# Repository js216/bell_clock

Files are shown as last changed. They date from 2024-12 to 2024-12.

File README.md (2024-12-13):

# Alarm clock with a real bell

These are the design files for a simple three-button alarm clock.

- `3d`: FreeCAD files for custom-fabricated parts
- `firmware`: code that runs on the clock Arduino
- `pcb`: KiCad files for the clock motherboard
- `top_plate`: KiCad files for the "front panel"

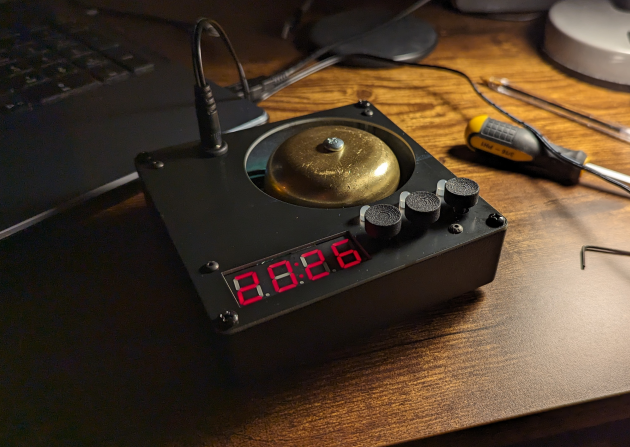
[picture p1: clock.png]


### Using the clock

#### Turning alarms on/off

Next to the time display, there are three buttons, each with an LED above it
associated with one of the three possible alarms.

A short press on these buttons cycles between three alarm modes for each of the
three alarms: alarm (and LED) off; single-chime mode (LED glows red); continuous
chime mode (LED glows green).

#### Setting the time

Pressing the first two buttons (i.e., left and middle button) simultaneously,
the time display begins flashing, signifying we're now in time setting mode. The
left button increments hours, the middle button increments minutes (resetting
seconds whenever it is pressed), and the right button is the "enter" button,
accepting the new time value.

#### Showing seconds

Pressing the middle and right buttons simultaneously, the display changes from
the usual HH:MM to MM:SS for five seconds.

#### Offset correction

The clock crystal is not perfect, and can be either fast or slow. To correct for
that, it is possible to either add or drop seconds periodically.

To enter the offset correction mode, press all three buttons simultaneously. The
display begins flashing very quickly, signifying we're in offset correction
mode. Left decrements the value, the middle button increments the value, and the
right button accepts the value.

The meaning of the offset value is as follows. For positive values, the time is
moved forward by a second every 433 minutes multiplied by the value. For
negative values, the time is moved backwards (i.e., the clock is slowed down) by
one second every 433 minutes multiplied by the absolute value of the offset
correction setting.

For example, if the offset correction value is set to -5, this means that every
5 times 433 minutes (approx 72.17 hours) a second is lost.

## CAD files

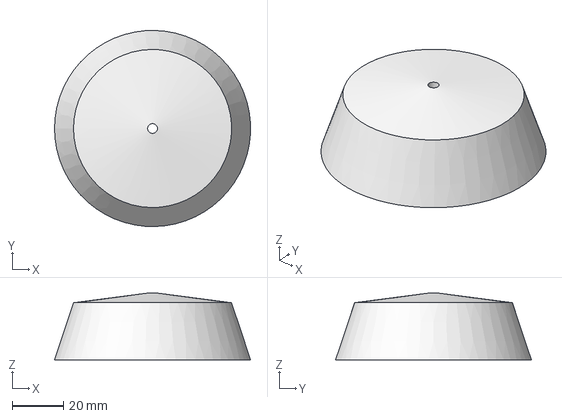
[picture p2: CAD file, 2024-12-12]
3d/bell.step
76.1 x 76.2 x 26.0 mm

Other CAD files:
3d/bell.FCStd

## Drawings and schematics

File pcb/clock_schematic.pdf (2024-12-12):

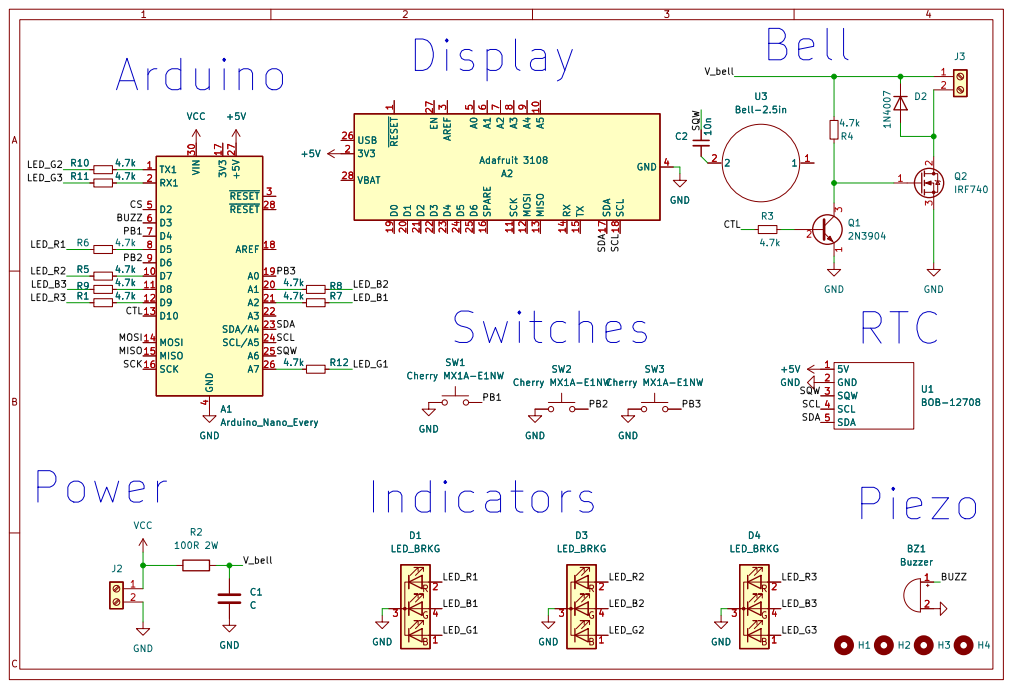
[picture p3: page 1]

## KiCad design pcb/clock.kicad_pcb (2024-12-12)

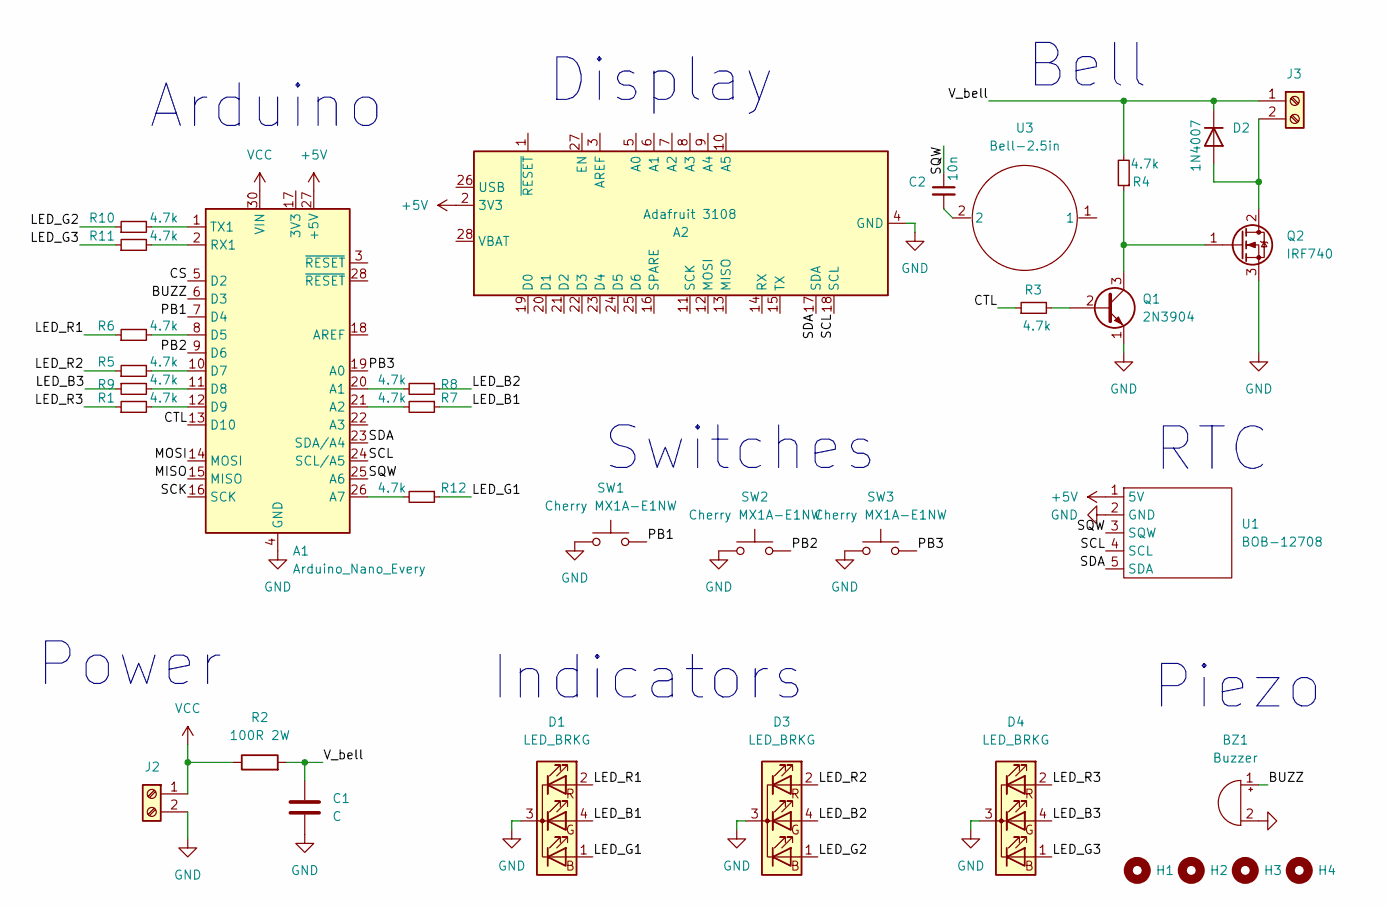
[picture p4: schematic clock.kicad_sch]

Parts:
A1: Arduino_Nano_Every; Arduino_Nano
A2: Adafruit 3108; Adafruit_Feather
BZ1: Buzzer; CP_Radial_Tantal_D10.5mm_P5.00mm
C1: C; CP_Radial_D10.0mm_P5.00mm
C2: 10n; CP_Axial_L10.0mm_D4.5mm_P15.00mm_Horizontal
D1, D3, D4: LED_BRKG; LED_D5.0mm-4_RGB
D2: 1N4007; D_DO-41_SOD81_P10.16mm_Horizontal
H1, H2, H3, H4: MountingHole; MountingHole_3.2mm_M3
J2, J3: Screw_Terminal_01x02; TerminalBlock_bornier-2_P5.08mm
Q1: 2N3904; TO-92_Inline
Q2: IRF740; TO-220-3_Horizontal_TabDown
R1, R3, R4, R5, R6, R7, R8, R9, R11, R12: 4.7k; R_Axial_DIN0207_L6.3mm_D2.5mm_P10.16mm_Horizontal
R2: 100R 2W; R_Axial_DIN0414_L11.9mm_D4.5mm_P15.24mm_Horizontal
R10: 4.7k; R_Axial_DIN0207_L6.3mm_D2.5mm_P7.62mm_Horizontal
SW1, SW2, SW3: Cherry MX1A-E1NW; SW_Cherry_MX_1.00u_PCB
U1: BOB-12708
U3: Bell-2.5in

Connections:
+5V: A1.27 (+5V), A2.2 (3V3), U1.1 (5V)
/BUZZ: A1.6 (D3), BZ1.1 (-)
/CS: A1.5 (D2)
/CTL: A1.13 (D10), R3.1
/LED_B1: D1.4 (GA), R7.1
/LED_B2: D3.4 (GA), R8.1
/LED_B3: D4.4 (GA), R9.1
/LED_G1: D1.1 (BA), R12.1
/LED_G2: D3.1 (BA), R10.1
/LED_G3: D4.1 (BA), R11.1
/LED_R1: D1.2 (RA), R6.1
/LED_R2: D3.2 (RA), R5.1
/LED_R3: D4.2 (RA), R1.1
/MISO: A1.15 (MISO)
/MOSI: A1.14 (MOSI)
/PB1: A1.7 (D4), SW1.2
/PB2: A1.9 (D6), SW2.2
/PB3: A1.19 (A0), SW3.2
/SCK: A1.16 (SCK)
/SCL: A1.24 (SCL/A5), A2.18 (SCL), U1.4 (SCL)
/SDA: A1.23 (SDA/A4), A2.17 (SDA), U1.5 (SDA)
/SQW: A1.25 (A6), C2.1, U1.3 (SQW)
/V_bell: C1.1, D2.1 (K), J3.1, R2.2, R4.2
GND: A1.4 (GND), A1.29 (GND), A2.4 (GND), BZ1.2 (+), C1.2, D1.3 (K), D3.3 (K), D4.3 (K), J2.2, Q1.1 (E), Q2.3 (S), SW1.1, SW2.1, SW3.1, U1.2 (GND)
unnamed: A1.1 (TX1), R10.2
unnamed: A1.2 (RX1), R11.2
unnamed: A1.8 (D5), R6.2
unnamed: A1.10 (D7), R5.2
unnamed: A1.11 (D8), R9.2
unnamed: A1.12 (D9), R1.2
unnamed: A1.20 (A1), R8.2
unnamed: A1.21 (A2), R7.2
unnamed: A1.26 (A7), R12.2
unnamed: C2.2, U3.2
unnamed: D2.2 (A), J3.2, Q2.2 (D)
unnamed: Q1.2 (B), R3.2
unnamed: Q1.3 (C), Q2.1 (G), R4.1
VCC: A1.30 (VIN), J2.1, R2.1

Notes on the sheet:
Bell
Switches
RTC
Indicators
Display
Piezo
Power
Arduino

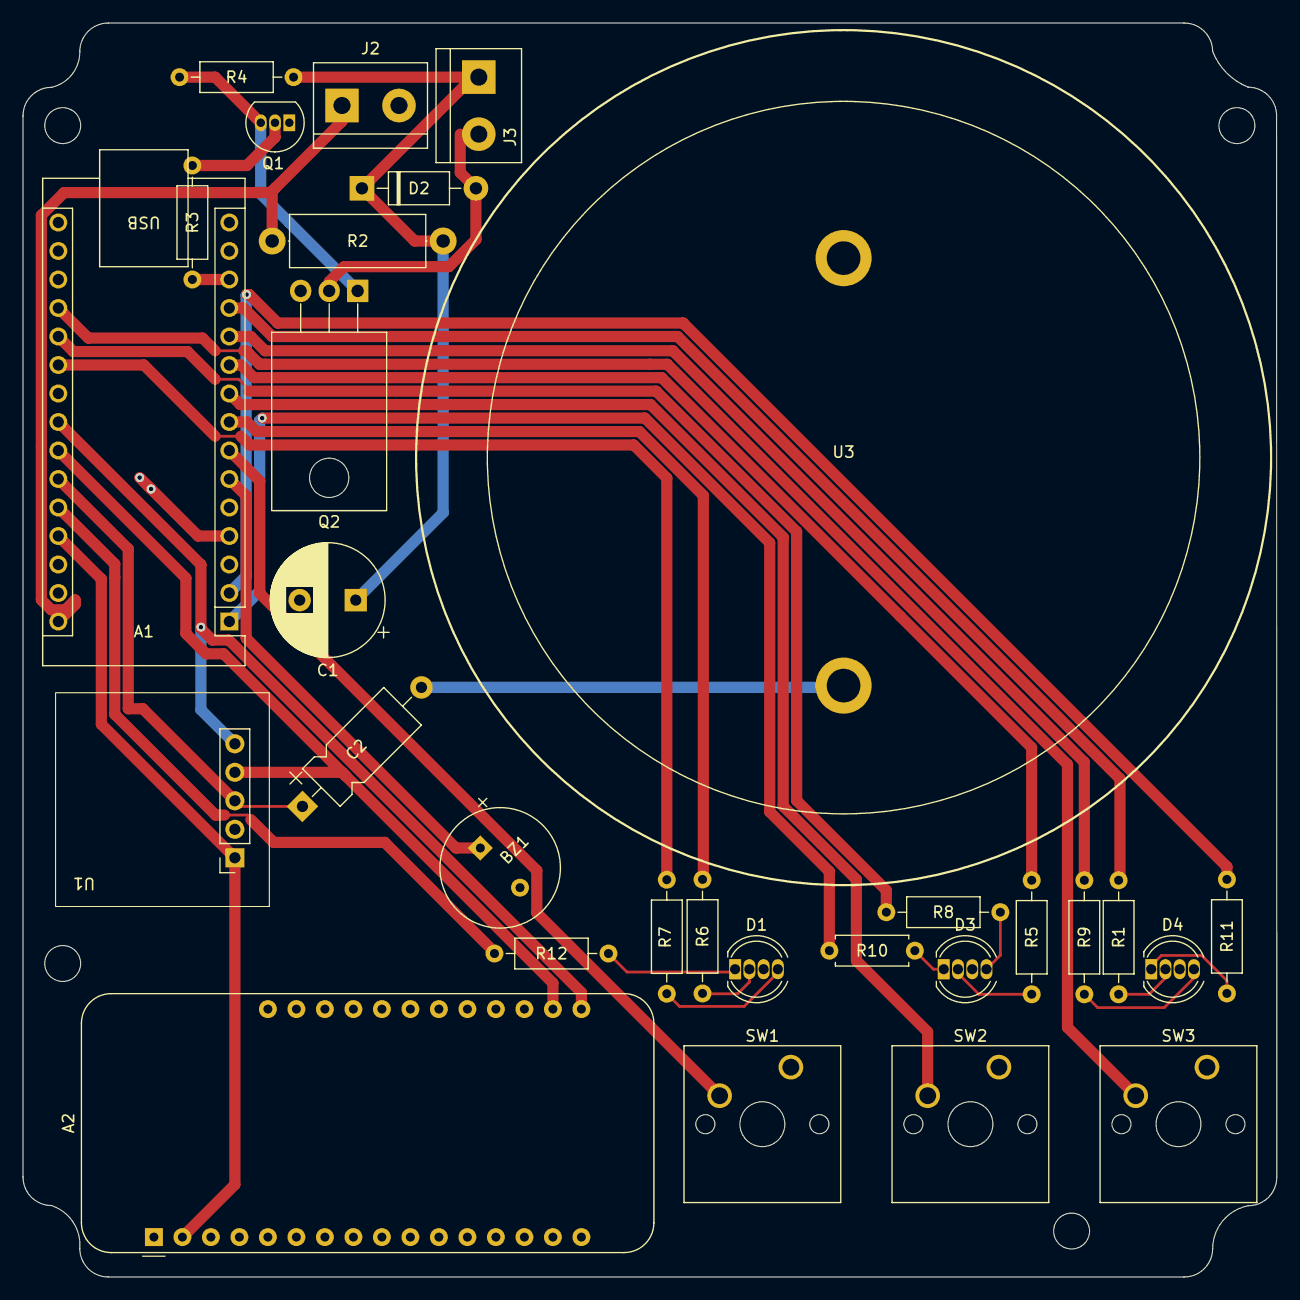
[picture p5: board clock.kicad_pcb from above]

Board: 2 copper layers, 111.7 x 111.8 mm, 34 parts (0 on the bottom side), 34 nets.

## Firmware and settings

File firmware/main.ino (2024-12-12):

/*
 * Simple three-button alarm clock.
 *
 * Jakob Kastelic, Stanford Research Systems.
 */

// Arduino libraries
#include <Wire.h>
#include <SPI.h>

// vendor-specific libraries
#include <Adafruit_GFX.h>
#include "SparkFunDS1307RTC.h"
#include "Adafruit_LEDBackpack.h"

// this application
#include "buttons.h"
#include "alarms.h"

// compile-time parameters
#define NUM_BTNS 3
#define NUM_ALARMS 3
#define SLOW_FLASHING 16
#define FAST_FLASHING 6
#define SUPER_FAST_FLASHING 3
#define SEC_DISPLAY_DURATION 5
#define OFFS_REG 12
#define SRAM_OFFS 8
#define OFFSET_TO_MIN 433

// modes for the state machine
enum {
   MODE_NORMAL,
   MODE_EDIT_ALARM,
   MODE_EDIT_TIME,
   MODE_DISPLAY_SECONDS,
   MODE_EDIT_XTAL,
};

// pin definitions
const int led_pin[][ALARM_NUM_COLORS] = {{5, A7, A2}, {7, 1, A1}, {9, 0, 8}};
const int btn_pin[] = {4, 6, A0};
const int buzz_pin = 3;
const int rtc_sqw_pin = A6;
const int ctl_pin = 10;

// global variables
volatile bool second_passed;
int hour, minute, second;
int mode, edit_sel;
int disp_sec_countdown;

// for offset correction
int8_t offset_interval;
bool offset_sign;
int min_to_correction;

// modules
Adafruit_7segment matrix = Adafruit_7segment();
btn_t btn_arr[NUM_BTNS];
alarm_t alarm_arr[NUM_ALARMS];

/**
 * Interrupt routine when the square wave pin gets a transition.
 */
void sqw_irq(void)
{
   second_passed = true;
}


void setup() {
   // buzzer
   pinMode(buzz_pin, OUTPUT);

   // setup RTC (SparkFun BOB-10160 using DS3234)
   rtc.begin();
   rtc.enable();
   rtc.set24Hour(true);
   rtc.update();
   rtc.writeSQW(SQW_SQUARE_1);
   pinMode(rtc_sqw_pin, INPUT_PULLUP);
   attachInterrupt(digitalPinToInterrupt(rtc_sqw_pin), sqw_irq, RISING);
   second = rtc.second();
   minute = rtc.minute();
   hour = rtc.hour();

   // offset correction
   offset_interval = rtc.i2cReadByte(DS1307_RTC_ADDRESS, SRAM_OFFS+OFFS_REG);
   min_to_correction = OFFSET_TO_MIN * abs(offset_interval);

   // setup LEDs
   for (int i=0; i<NUM_BTNS; i++)
      for (int j=0; j<ALARM_NUM_COLORS; j++)
         if (j == 0)
            pinMode(led_pin[i][j], OUTPUT);
         else // for green & blue, use pullup resistor to make them less bright
            pinMode(led_pin[i][j], INPUT);

   // setup buttons
   for (int i=0; i<NUM_BTNS; i++) {
      btn_arr[i].pin = btn_pin[i];
      btn_init(&(btn_arr[i]));
   }

   // setup display (Adafruit 3108 using HT16K33 driver)
   matrix.begin(0x70);
   matrix.setBrightness(0);

   // setup alarms
   pinMode(ctl_pin, OUTPUT);
   digitalWrite(ctl_pin, HIGH);
   for (int i=0; i<NUM_ALARMS; i++) {
      alarm_arr[i].hour    = rtc.i2cReadByte(DS1307_RTC_ADDRESS, SRAM_OFFS+4*i);
      alarm_arr[i].min     = rtc.i2cReadByte(DS1307_RTC_ADDRESS, SRAM_OFFS+4*i+1);
      alarm_arr[i].mode    = rtc.i2cReadByte(DS1307_RTC_ADDRESS, SRAM_OFFS+4*i+2);
      alarm_arr[i].single  = rtc.i2cReadByte(DS1307_RTC_ADDRESS, SRAM_OFFS+4*i+3);
      alarm_arr[i].ctl_pin = ctl_pin;
      for (int j=0; j<ALARM_NUM_COLORS; j++)
         alarm_arr[i].led_pin[j] = led_pin[i][j];
      alarm_led(&(alarm_arr[i]), true);
   }
}


void loop() {
   // every second
   if (second_passed) {
      // clear flag
      second_passed = false;

      // offset correction
      int dt = 1;
      if (second == 0) {
         if (min_to_correction == 0) {
            if (offset_interval > 0)
               dt = 2; // insert a second
            else if (offset_interval < 0)
               dt = 0; // skip a second
            min_to_correction = OFFSET_TO_MIN * abs(offset_interval);
         } else {
            dt = 1;
            min_to_correction--;
         }
      }

      // advance time
      if (second+dt >= 60) {
         if (minute == 59)
            hour = (hour + 1) % 24;
         minute = (minute + 1) % 60;
      }
      second = (second + dt) % 60;

      // record offset correction to RTC
      if (dt != 1) {
         rtc.setHour(hour);
         rtc.setMinute(minute);
         rtc.setSecond(second);
      }

      // make a clicking sound
      digitalWrite(buzz_pin, HIGH);
      digitalWrite(buzz_pin, LOW);

      // check alarms
      for (int i=0; i<NUM_ALARMS; i++)
         alarm_check(&(alarm_arr[i]), hour, minute);

      // exit "display seconds" mode when countdown expires
      if (disp_sec_countdown >= 1)
         disp_sec_countdown--;
      if (disp_sec_countdown == 1)
         mode = MODE_NORMAL;

      // flash the colon on the display
      static bool display_colon;
      display_colon = !display_colon;
      matrix.drawColon(display_colon);
      matrix.writeDisplay();
   }

   // update alarms, display, and buttons
   sram_update();
   display_flash();
   display_update();
   check_buttons();

   // loop delay
   delay(50);
}


void sram_update(void)
{
   for (int i=0; i<NUM_ALARMS; i++) {
      if (! (alarm_arr[i].updated)) {
         rtc.i2cWriteByte(DS1307_RTC_ADDRESS, SRAM_OFFS+4*i,   (uint8_t)alarm_arr[i].hour);
         rtc.i2cWriteByte(DS1307_RTC_ADDRESS, SRAM_OFFS+4*i+1, (uint8_t)alarm_arr[i].min);
         rtc.i2cWriteByte(DS1307_RTC_ADDRESS, SRAM_OFFS+4*i+2, (uint8_t)alarm_arr[i].mode);
         rtc.i2cWriteByte(DS1307_RTC_ADDRESS, SRAM_OFFS+4*i+3, (uint8_t)alarm_arr[i].single);
      }
   }
}


void display_flash(void)
{
   // do not flash in normal mode
   if (mode == MODE_NORMAL)
      return;

   // determine flashing rate
   unsigned int rate = -1;
   if (mode == MODE_EDIT_ALARM)
      rate = SLOW_FLASHING;
   else if (mode == MODE_EDIT_TIME)
      rate = FAST_FLASHING;
   else if (mode == MODE_EDIT_XTAL)
      rate = SUPER_FAST_FLASHING;

   // counter to control screen flashing
   static unsigned int loop_iteration;
   loop_iteration++;

   // flash the screen and LEDs
   if (loop_iteration % rate == rate-1) {
      loop_iteration = 0;
      matrix.setBrightness(5);
      if (mode == MODE_EDIT_ALARM)
         alarm_led(&(alarm_arr[edit_sel]), true);
   } else if (loop_iteration % (rate/2) == (rate/2)-1) {
      matrix.setBrightness(0);
      if (mode == MODE_EDIT_ALARM)
         alarm_led(&(alarm_arr[edit_sel]), false);
   }
}


void display_update(void)
{
   // to keep track when display needs updating
   static int old_num=-1;
   int new_num=-1;

   // determine what to display
   if ((mode == MODE_NORMAL) || (mode == MODE_EDIT_TIME))
      new_num = hour*100 + minute;
   else if (mode == MODE_EDIT_ALARM)
      new_num = alarm_arr[edit_sel].hour*100 + alarm_arr[edit_sel].min;
   else if (mode == MODE_DISPLAY_SECONDS)
      new_num = minute*100 + second;
   else if (mode == MODE_EDIT_XTAL) {
      new_num = offset_interval;
   } else
      new_num = 0;

   // sanity check the number
   if (new_num > 9999)
      new_num = 9999;
   else if (new_num < -999)
      new_num = -999;

   // update display if needed
   if (old_num != new_num) {
      // write digits
      if (mode == MODE_EDIT_XTAL)
         matrix.println(new_num);
      else {
         matrix.writeDigitNum(0, (new_num/1000)%10, false);
         matrix.writeDigitNum(1, (new_num/100 )%10, false);
         matrix.writeDigitNum(3, (new_num/10  )%10, false);
         matrix.writeDigitNum(4, (new_num/1   )%10, false);
      }

      // flush data to display
      matrix.writeDisplay();
      old_num = new_num;
   }
}


void check_buttons(void)
{
   // check if buttons were pressed
   for (int i=0; i<NUM_BTNS; i++)
      btn_update(&(btn_arr[i]));

   // if any button pressed, silence all active alarms
   for (int i=0; i<NUM_BTNS; i++)
      if (btn_arr[i].pressed) {
         for (int j=0; j<NUM_ALARMS; j++)
            if (alarm_arr[i].mode == ALARM_ACTIVE)
               alarm_arr[i].mode = ALARM_DONE;
         break;
      }

   // button presses in normal mode
   if (mode == MODE_NORMAL) {
      for (int i=0; i<NUM_BTNS; i++) {
         // check if all three buttns were pressed at the same time
         if (btn_three_pressed(&(btn_arr[0]), &(btn_arr[1]),
                  &(btn_arr[2]))) {
            detachInterrupt(digitalPinToInterrupt(rtc_sqw_pin));
            rtc.writeSQW(SQW_SQUARE_4K);
            mode = MODE_EDIT_XTAL;
         }

         // check if buttons 0 & 1 were pressed at the same time
         else if (btn_two_pressed(&(btn_arr[0]), &(btn_arr[1])))
            mode = MODE_EDIT_TIME;

         // check if buttons 1 & 2 were pressed at the same time
         else if (btn_two_pressed(&(btn_arr[1]), &(btn_arr[2]))) {
            disp_sec_countdown = (SEC_DISPLAY_DURATION + 1);
            mode = MODE_DISPLAY_SECONDS;
         }

         // short button press: cycle alarm modes
         else if (btn_was_pressed(&(btn_arr[i]))) {
            alarm_cycle(&(alarm_arr[i]), +1, hour, minute);
         }

         // long button press: enter alarm edit mode
         else if (btn_was_longpressed(&(btn_arr[i]))) {
            btn_was_repressed(&(btn_arr[i]));
            alarm_cycle(&(alarm_arr[i]), -1, hour, minute);
            mode = MODE_EDIT_ALARM;
            edit_sel = i;
         }
      }
   }

   // button presses in alarm edit mode
   else if (mode == MODE_EDIT_ALARM) {
      // short (or held) press on button 0: increment hours
      if ((btn_was_pressed(&(btn_arr[0])))
            || (btn_was_repressed(&(btn_arr[0])))) {
         alarm_arr[edit_sel].updated = false;
         alarm_arr[edit_sel].hour = (alarm_arr[edit_sel].hour + 1) % 24;
      }

      // short (or held) press on button 1: increment minutes
      if ((btn_was_pressed(&(btn_arr[1])))
            || (btn_was_repressed(&(btn_arr[1])))) {
         alarm_arr[edit_sel].updated = false;
         alarm_arr[edit_sel].min = (alarm_arr[edit_sel].min + 1) % 60;
      }

      // short press on button 2: exit edit mode
      if (btn_was_pressed(&(btn_arr[2]))) {
         alarm_led(&(alarm_arr[edit_sel]), true);
         matrix.setBrightness(0);
         mode = MODE_NORMAL;
      }
   }

   // button presses in time edit mode
   else if (mode == MODE_EDIT_TIME) {
      // short (or held) press btn 0: increment hours
      if ((btn_was_pressed(&(btn_arr[0])))
            || (btn_was_repressed(&(btn_arr[0])))) {
         hour = (hour + 1) % 24;
         rtc.setHour(hour);
      }

      // short (or held) press btn 1: increment min & zero the sec
      if ((btn_was_pressed(&(btn_arr[1])))
            || (btn_was_repressed(&(btn_arr[1])))) {
         minute = (minute + 1) % 60;
         second = 0;
         rtc.setMinute(minute);
         rtc.setSecond(second);
         min_to_correction = OFFSET_TO_MIN * abs(offset_interval);
      }

      // short press on button 2: exit edit mode
      if (btn_was_pressed(&(btn_arr[2]))) {
         matrix.setBrightness(0);
         mode = MODE_NORMAL;
      }
   }

   // button presses in xtal aging offset edit mode
   else if (mode == MODE_EDIT_XTAL) {
      // short (or held) press btn 0: decrement offset
      if ((btn_was_pressed(&(btn_arr[0])))
            || (btn_was_repressed(&(btn_arr[0]))))
         offset_interval--;

      // short (or held) press btn 1: increment offset
      if ((btn_was_pressed(&(btn_arr[1])))
            || (btn_was_repressed(&(btn_arr[1]))))
         offset_interval++;

      // short press on button 2: exit edit xtal mode
      if (btn_was_pressed(&(btn_arr[2]))) {
         // write offset to register
         rtc.i2cWriteByte(DS1307_RTC_ADDRESS, SRAM_OFFS+OFFS_REG, offset_interval);
         min_to_correction = OFFSET_TO_MIN * abs(offset_interval);

         // update time from RTC
         rtc.update();
         second = rtc.second();
         minute = rtc.minute();
         hour = rtc.hour();

         // stop flashing the display
         matrix.setBrightness(0);

         // move to normal mode
         mode = MODE_NORMAL;

         // reattach "per second" interrupt
         rtc.writeSQW(SQW_SQUARE_1);
         attachInterrupt(digitalPinToInterrupt(rtc_sqw_pin), sqw_irq, FALLING);
      }
   }
}

// end file clock2.ino

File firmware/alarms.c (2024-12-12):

/*
 * Mini-library for alarms.
 *
 * Jakob Kastelic (Stanford Research Systems)
 */

#include "Arduino.h"
#include "alarms.h"

void alarm_check(alarm_t *alarm, const int h, const int m)
{
    // if alarm is armed, it goes off when it's time
    if (alarm->mode == ALARM_ARMED) {
        if ((h == alarm->hour) && (m == alarm->min)) {
            alarm->mode = ALARM_ACTIVE;
            alarm->counter = 0;
        }
    }

    // when alarm is in active state, count till we turn it off
    else if (alarm->mode == ALARM_ACTIVE) {
        alarm->counter++;

        // sound alarm at the ALARM_RATE
        if (alarm->counter % ALARM_RATE == ALARM_RATE-1) {
            // reset counter so it doesn't eventually overflow
            alarm->counter = 0;

            // issue bell pulse
            digitalWrite(alarm->ctl_pin, LOW);
            delay(BELL_DURATION);
            digitalWrite(alarm->ctl_pin, HIGH);

            // in one-shot mode, turn alarm off when it expires
            if (alarm->single)
                alarm->mode = ALARM_DONE;
        }
    }

    // when alarm is done, wait to re-arm
    else if (alarm->mode == ALARM_DONE) {
        if ((h != alarm->hour) || (m != alarm->min))
            alarm->mode = ALARM_ARMED;
    }
}


void alarm_cycle(alarm_t *alarm, const int dir, const int h, const int m)
{
    // cycle in the positive direction
    if (dir > 0) {
        if ((alarm->mode == ALARM_ARMED) || (alarm->mode == ALARM_DONE)) {
            if (alarm->single)
                alarm->single = false;
            else
                alarm->mode = ALARM_OFF;
        } else { // if not armed or done
            alarm->single = true;
            if ((h != alarm->hour) || (m != alarm->min))
                alarm->mode = ALARM_ARMED;
            else
                alarm->mode = ALARM_DONE;
        }
    }

    // cycle in the negative direction
    if (dir < 0) {
        if ((alarm->mode == ALARM_ARMED) || (alarm->mode == ALARM_DONE)) {
            if (alarm->single)
                alarm->mode = ALARM_OFF;
            else
                alarm->single = true;
        } else { // if not armed or done
            alarm->single = false;
            alarm->mode = ALARM_ARMED;
        }
    }

    // after cycling, SRAM data and LED state is out of date
    alarm->updated = false;
    alarm_led(alarm, true);
}


void alarm_led(alarm_t *alarm, const bool mode)
{
   if ((alarm->mode == ALARM_OFF) || (mode == false))
      for (int j=0; j<ALARM_NUM_COLORS; j++)
         digitalWrite(alarm->led_pin[j], LOW);
   else {
      if (alarm->single) {
         digitalWrite(alarm->led_pin[0], HIGH);
         digitalWrite(alarm->led_pin[1], LOW);
         digitalWrite(alarm->led_pin[2], LOW);
      } else {
         digitalWrite(alarm->led_pin[0], LOW);
         digitalWrite(alarm->led_pin[1], HIGH);
         digitalWrite(alarm->led_pin[2], LOW);
      }
   }
}

// end file alarms.c
